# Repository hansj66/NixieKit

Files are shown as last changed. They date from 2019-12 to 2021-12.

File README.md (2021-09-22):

# Nixie Clock Kit 1.3

This repository contains firmware examples and the necessary STEP files for completing the TimeExpander Nixie Clock Kit. 

You will need to patch the 595 driver for the wiringPi and invert the logic before compiling the firmware.

The PDF in the "doc" folder contains assembly instructions / bill of materials

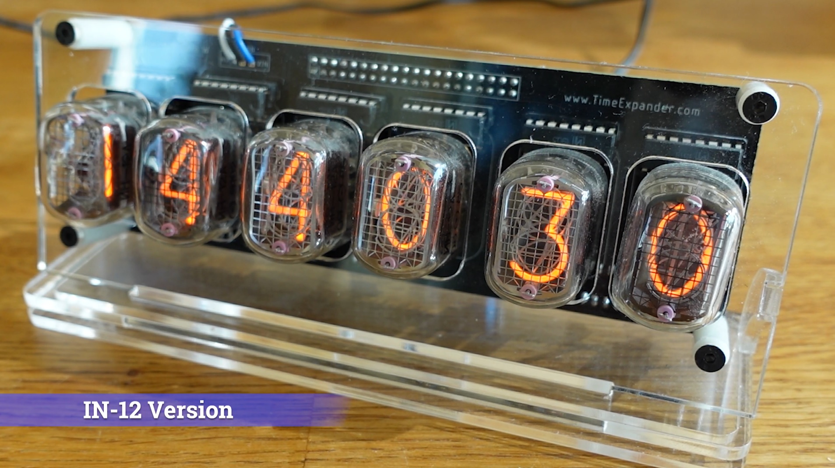
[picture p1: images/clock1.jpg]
clock1


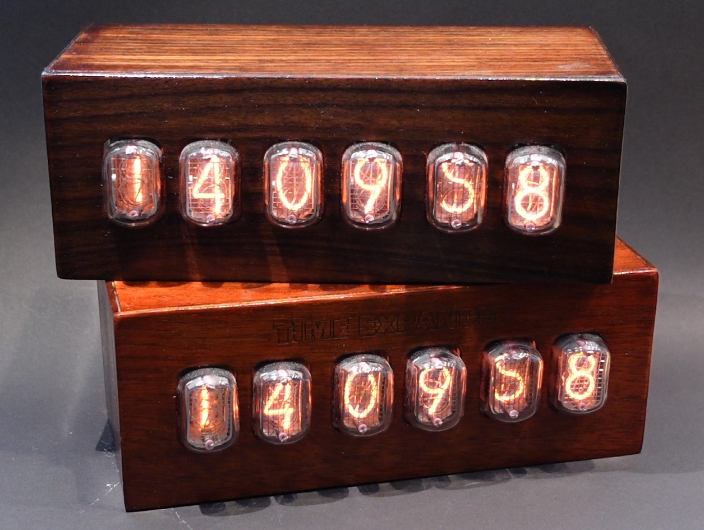
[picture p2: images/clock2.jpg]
clock2


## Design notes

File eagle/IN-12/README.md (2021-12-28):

# Experimental IN-1 variant of the IN-12 clock.

This is pin compatible with the IN-12 clock and will run the same firmware.

# IMPORTANT NOTE

1. The Board is designed for use with Mill-Max pin sockets (Manufacturer Product Number: 0390-0-15-01-08-27-10-0. DigiKey part number: [ED5034-ND](https://www.digikey.no/en/products/detail/mill-max-manufacturing-corp/0390-0-15-01-08-27-10-0/158196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))

2. The alignment of the digits with respect to the pinout have been off by a certain degree on almost all of the tubes that I have tested. I would advise against soldering the mill max sockets to the PCB if you have a limited number of tubes available, since the odds are that the aligment of the digits will vary noticeably between digits.

If you care about perfect alignment of the digits and only have a limited number of IN-1 tubes available, a better option might be to use Molex crimp terminals as pin sockets for the tubes (DigiKey part number [WM1103-ND](https://www.digikey.no/en/products/detail/molex/0002091119/26390?s=N4IgTCBcDaIO4FsCMSAMBmAtAOwCYgF0BfIA)) and run wires between the crimp terminals and the board.

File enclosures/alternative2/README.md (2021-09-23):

# Note

The DXF files are suitable laser cutting parts using 3mm materials

There are no air vents in this design. The clock has been tested in this enclosure for durations of up to 8 hours during mini maker faires.

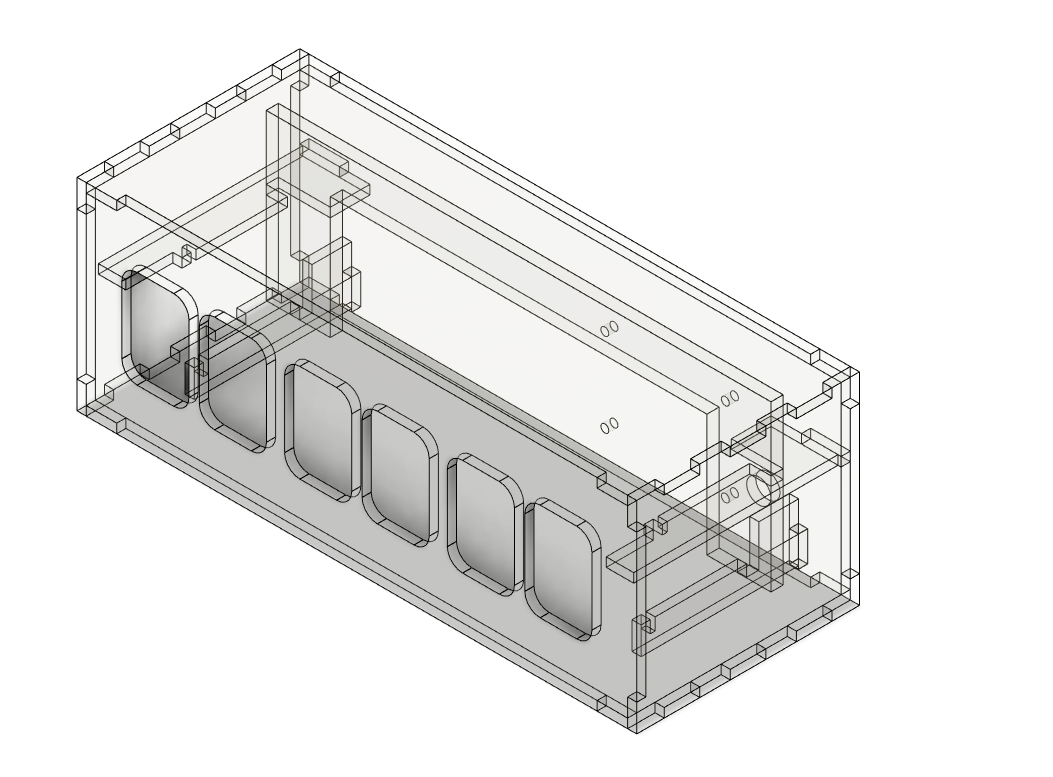
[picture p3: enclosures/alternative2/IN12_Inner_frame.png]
inner frame


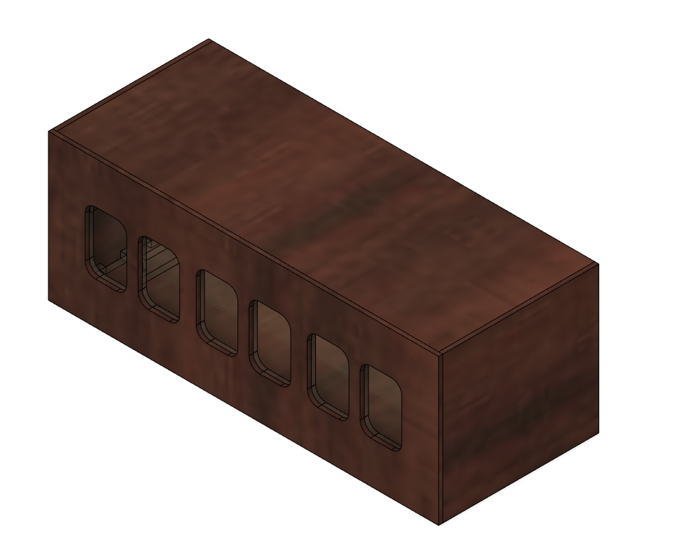
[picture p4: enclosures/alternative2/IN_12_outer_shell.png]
outer shell


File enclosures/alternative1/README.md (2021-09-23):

# Note

The DXF files are suitable laser cutting parts using 3mm materials

# Warning

By mounting the PCB in this frame, the high voltage anode pins will be exposed at the rear.

If using this design, the clock should be placed in a safe area / display cabinet.

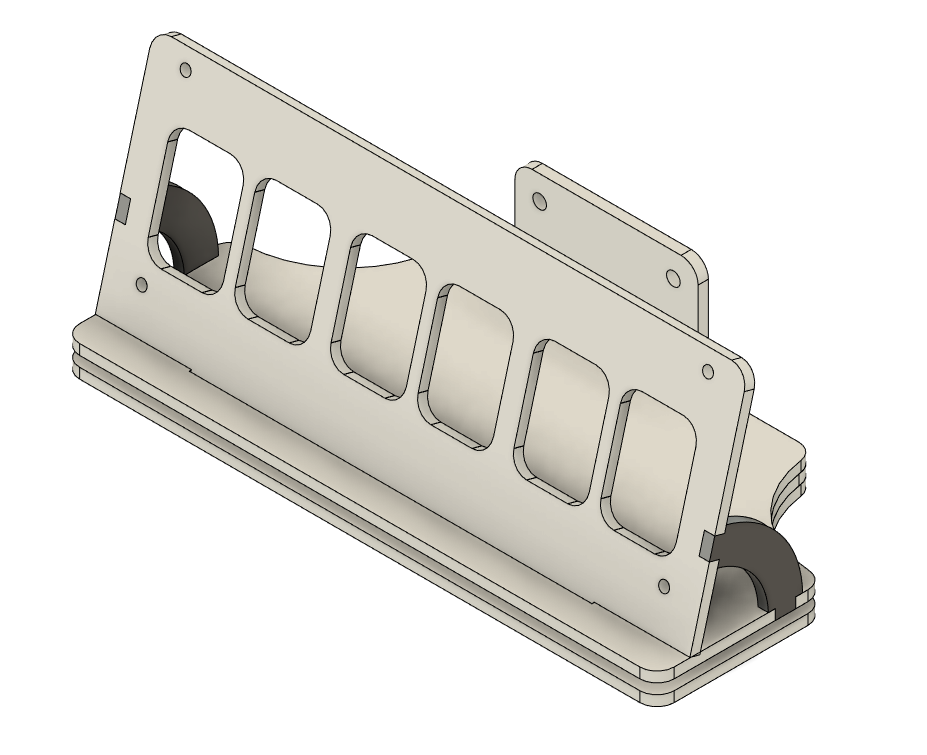
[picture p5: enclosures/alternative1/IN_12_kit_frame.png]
frame


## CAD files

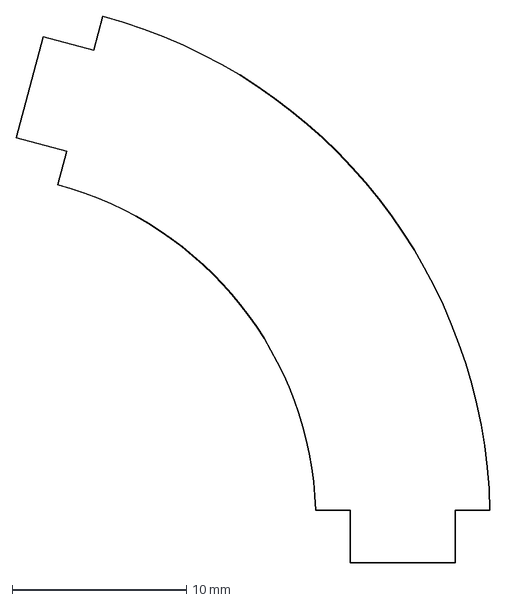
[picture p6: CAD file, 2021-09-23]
enclosures/alternative1/DXF/Side_bracket2.dxf
27.2 x 31.3 mm

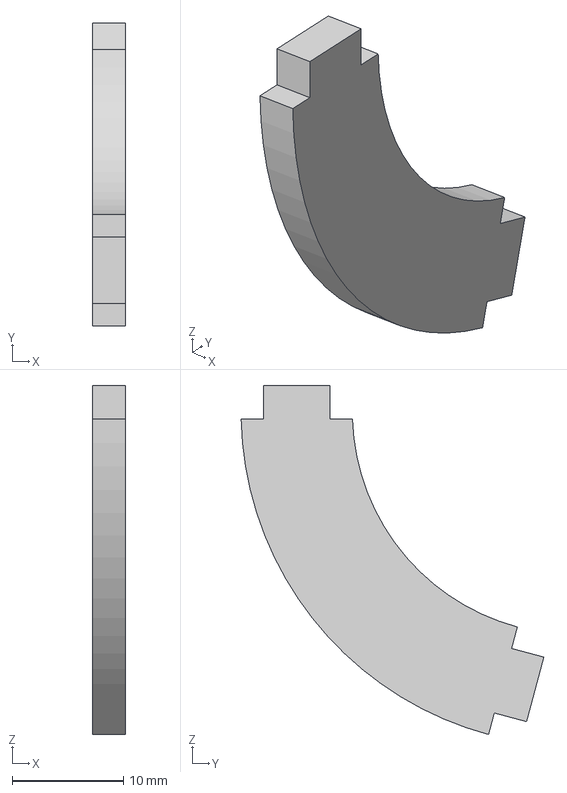
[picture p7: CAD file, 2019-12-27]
enclosures/alternative1/STEP/side1.step
3.00 x 27.2 x 31.3 mm

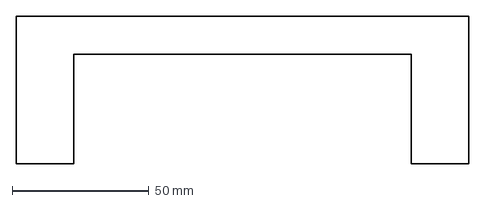
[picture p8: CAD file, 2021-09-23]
enclosures/alternative2/DXF/Rear_bracket.dxf
165.5 x 54.0 mm

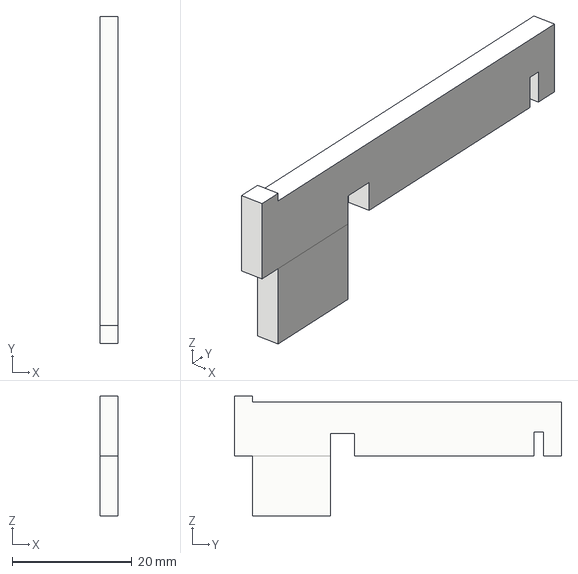
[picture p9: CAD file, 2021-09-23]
enclosures/alternative2/STEP/PCB_Bracket4.step
3.00 x 54.6 x 20.0 mm

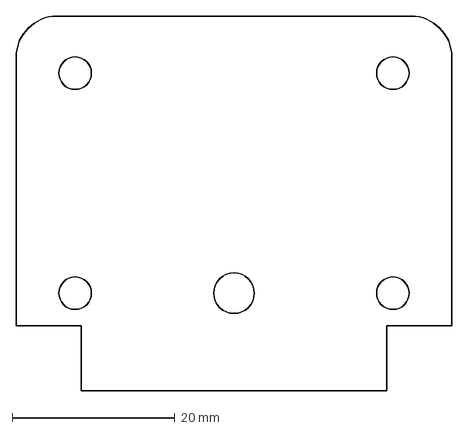
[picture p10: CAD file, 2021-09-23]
enclosures/alternative1/DXF/Power.dxf
53.5 x 46.0 mm

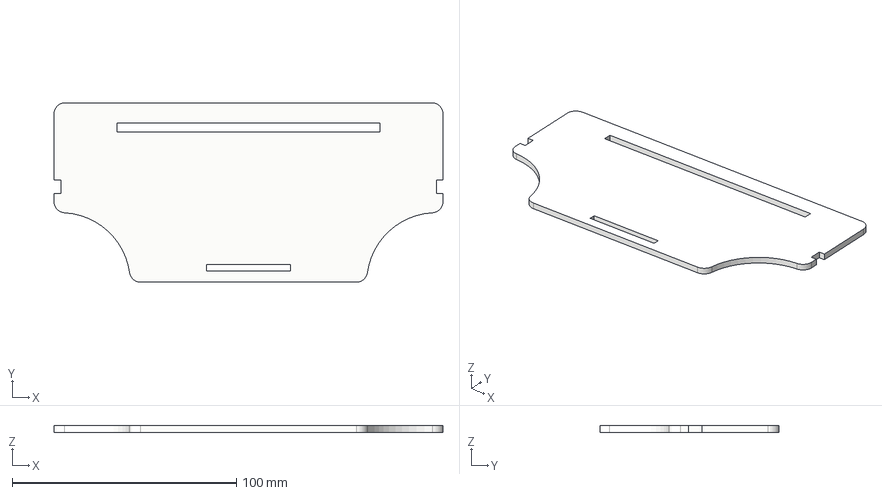
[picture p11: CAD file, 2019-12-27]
enclosures/alternative1/STEP/base_top.step
173.5 x 80.0 x 3.00 mm

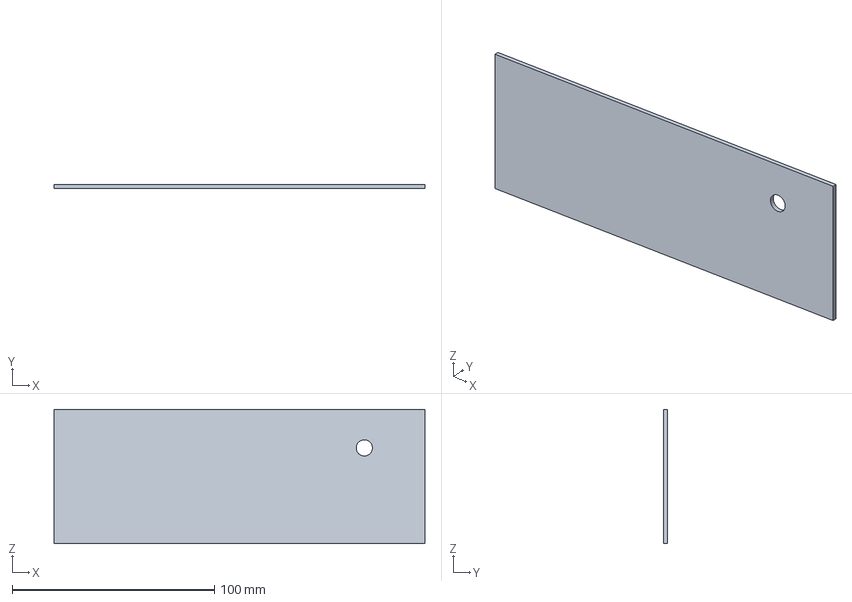
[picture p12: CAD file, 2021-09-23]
enclosures/alternative2/STEP/Wood_Back.step
183.5 x 2.00 x 66.3 mm

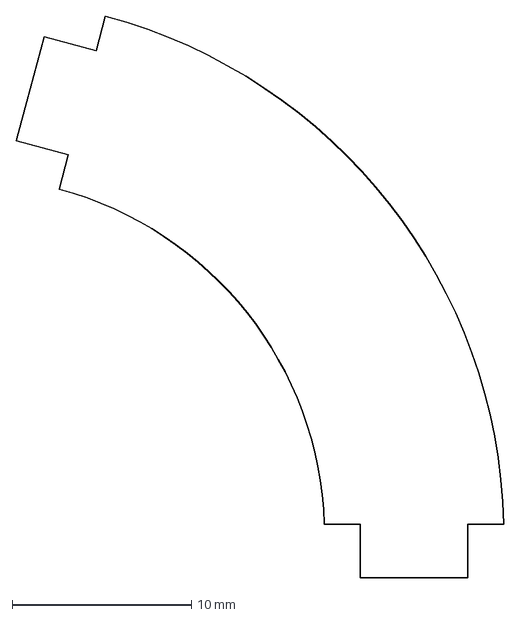
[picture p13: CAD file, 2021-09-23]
enclosures/alternative1/DXF/Side_bracket1.dxf
27.2 x 31.3 mm

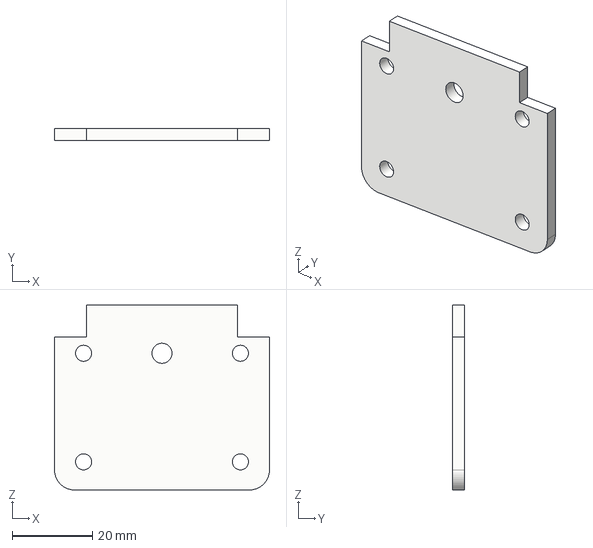
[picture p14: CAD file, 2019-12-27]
enclosures/alternative1/STEP/HV.step
53.5 x 3.00 x 46.0 mm

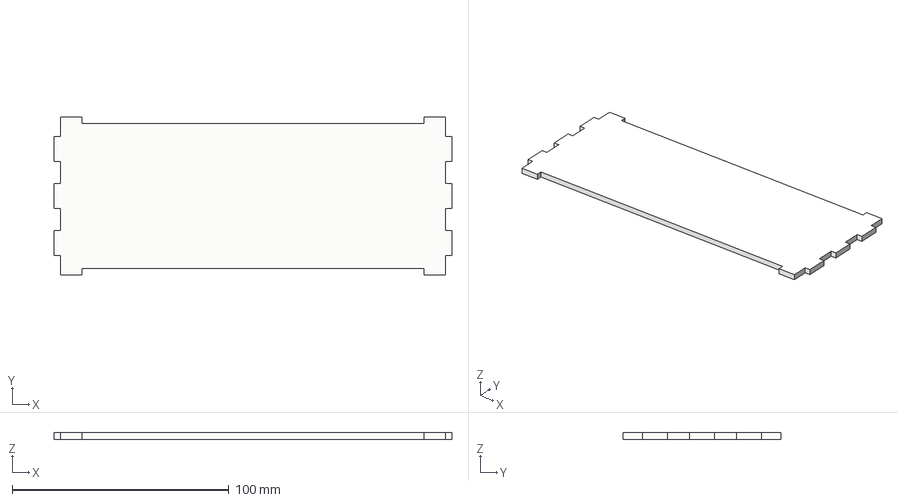
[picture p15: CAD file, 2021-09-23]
enclosures/alternative2/STEP/Bottom.step
183.5 x 73.0 x 3.00 mm

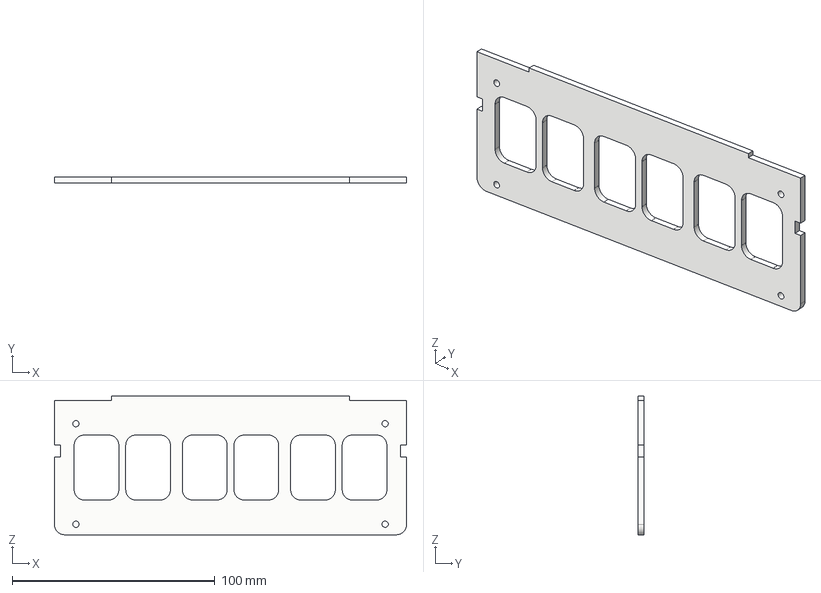
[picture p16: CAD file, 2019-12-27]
enclosures/alternative1/STEP/front.step
173.5 x 3.00 x 68.3 mm

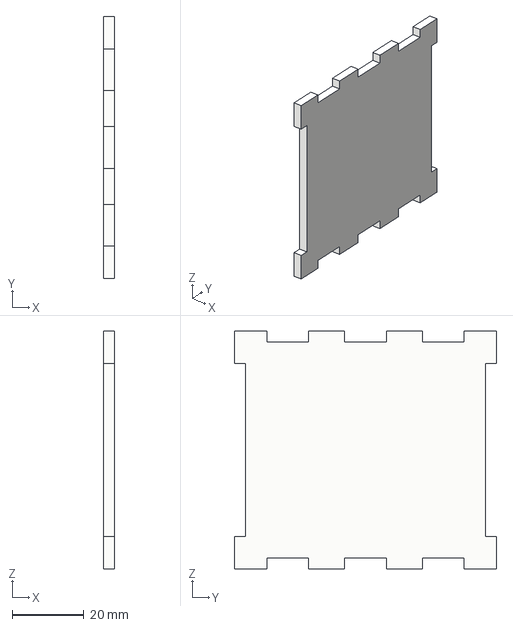
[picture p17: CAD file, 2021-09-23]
enclosures/alternative2/STEP/Right_Side.step
3.00 x 73.0 x 66.3 mm

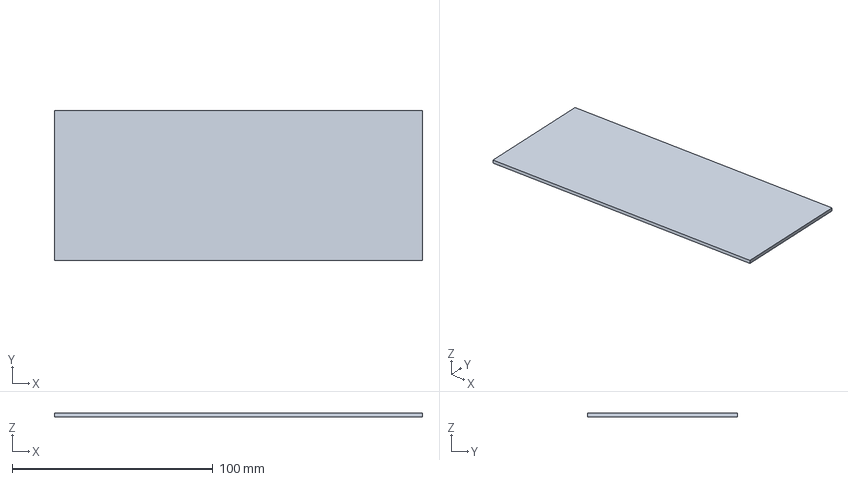
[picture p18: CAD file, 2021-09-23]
enclosures/alternative2/STEP/Wood_Top.step
183.5 x 75.0 x 2.00 mm

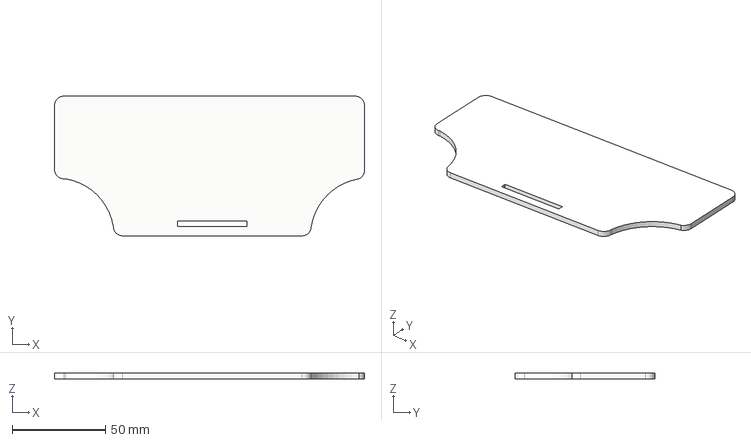
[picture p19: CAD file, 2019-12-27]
enclosures/alternative1/STEP/base_middle.step
166.5 x 75.0 x 3.00 mm

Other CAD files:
enclosures/alternative1/STEP/side2.step
enclosures/alternative2/STEP/Left_Side.step
enclosures/alternative1/STEP/base_bottom.step
enclosures/alternative2/STEP/PCB_Bracket3.step
enclosures/alternative1/DXF/Base_bottom.dxf
enclosures/alternative1/DXF/Base_middle.dxf
enclosures/alternative1/DXF/Base_top.dxf
enclosures/alternative1/DXF/Front.dxf
enclosures/alternative2/DXF/Back.dxf
enclosures/alternative2/DXF/Bottom.dxf
enclosures/alternative2/DXF/Front.dxf
enclosures/alternative2/DXF/Left_Side.dxf
enclosures/alternative2/DXF/PCB_Bracket1.dxf
enclosures/alternative2/DXF/PCB_Bracket2.dxf
enclosures/alternative2/DXF/PCB_Bracket3.dxf
enclosures/alternative2/DXF/PCB_Bracket4.dxf
enclosures/alternative2/DXF/Right_side.dxf
enclosures/alternative2/DXF/Top.dxf
enclosures/alternative2/DXF/Wood_back.dxf
enclosures/alternative2/DXF/Wood_bottom.dxf
enclosures/alternative2/DXF/Wood_front.dxf
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

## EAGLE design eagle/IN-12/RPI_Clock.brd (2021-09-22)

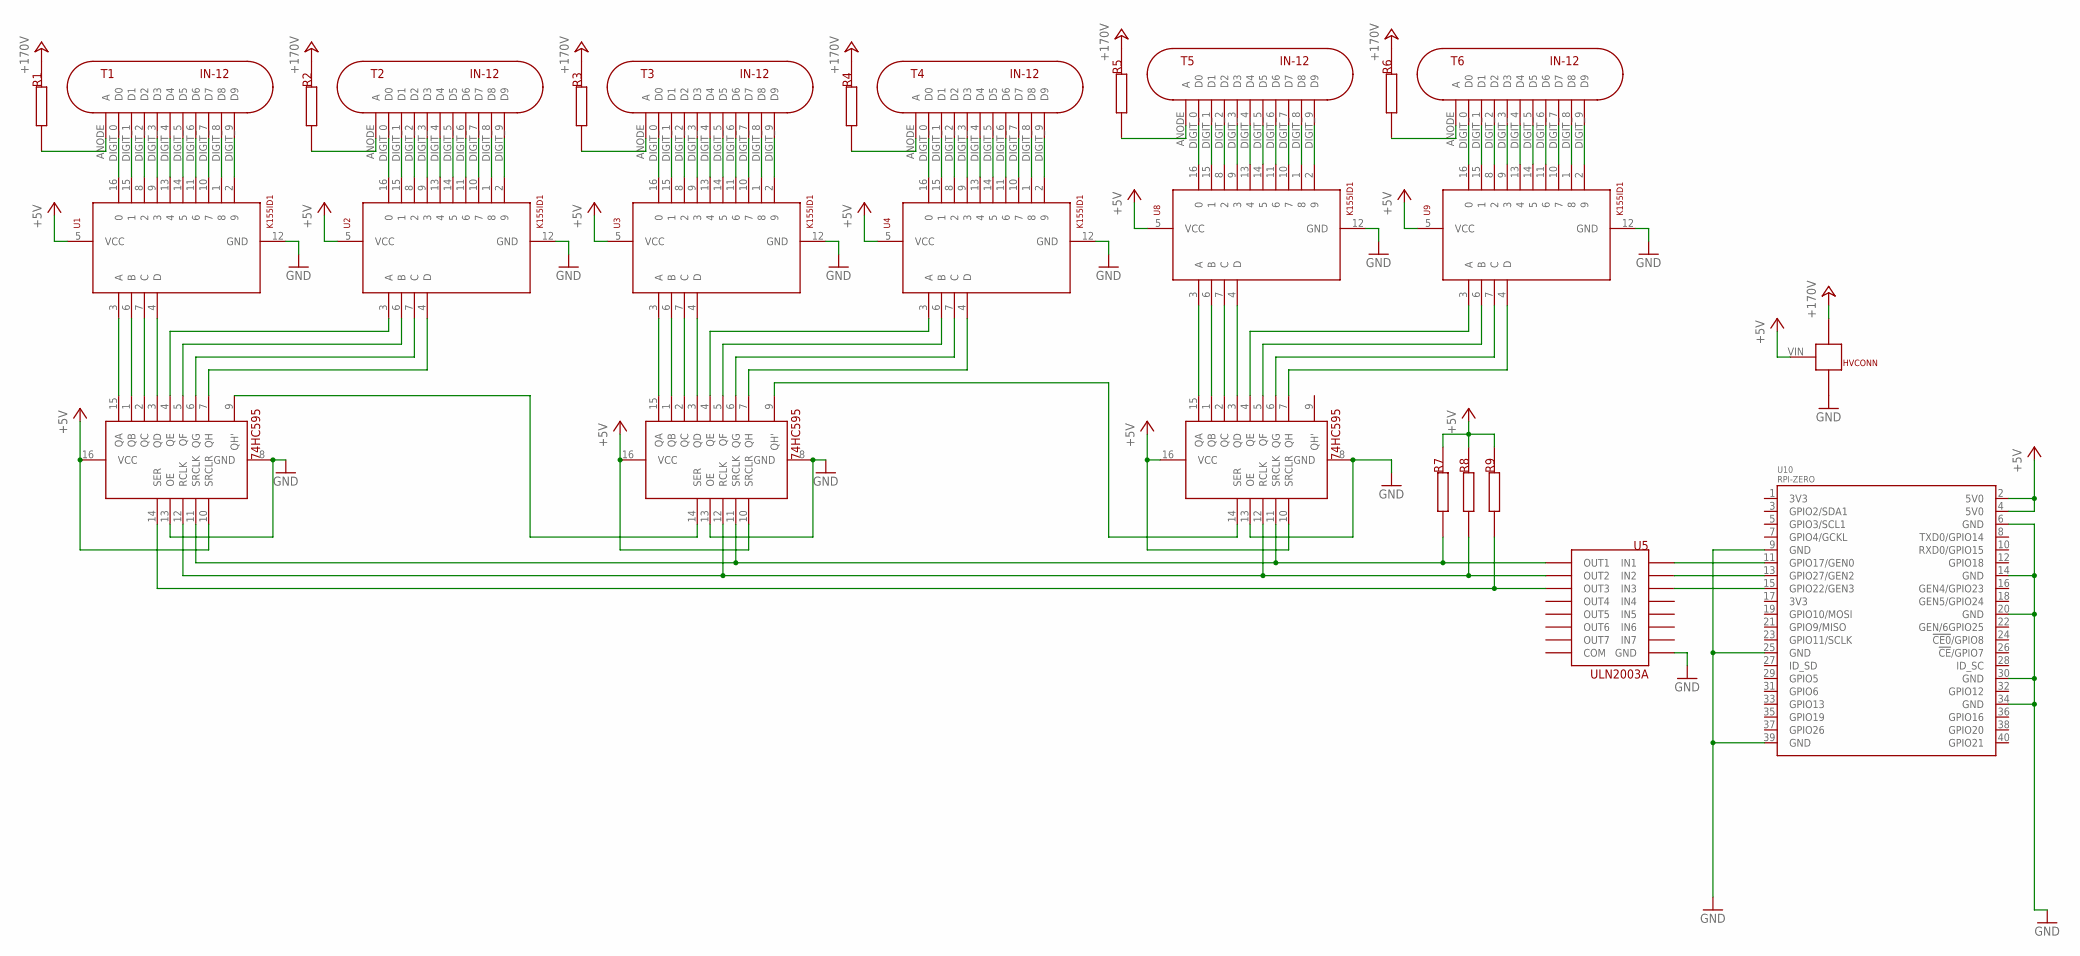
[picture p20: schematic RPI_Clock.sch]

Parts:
HVCONN: HV_CONNECTOR
R1, R2, R3, R4, R5, R6: 5,6K; ANODE_RESISTOR
R7, R8, R9: 10k; ANODE_RESISTOR
T1, T2, T3, T4, T5, T6: IN-12
U1, U2, U3, U4, U8, U9: K155ID1; DIP16-2.54-19.2X7.62MM
U5: ULN2003A; DIL16
U6, U7, U11: 74HC595; DIL16
U10: RPI-ZERO; RASP_PI_ZERO_BOARD_FULL

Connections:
+5V: HVCONN.VIN, R7.P$2, R8.P$2, R9.P$2, U1.5 (VCC), U2.5 (VCC), U3.5 (VCC), U4.5 (VCC), U6.10 (SRCLR), U6.16 (VCC), U7.10 (SRCLR), U7.16 (VCC), U8.5 (VCC), U9.5 (VCC), U10.2 (5V0), U10.4 (5V0), U11.10 (SRCLR), U11.16 (VCC)
+24V: HVCONN.+170V, R1.P$2, R2.P$2, R3.P$2, R4.P$2, R5.P$2, R6.P$2
GND: HVCONN.GND, U1.12 (GND), U2.12 (GND), U3.12 (GND), U4.12 (GND), U5.8 (GND), U6.8 (GND), U6.13 (OE), U7.8 (GND), U7.13 (OE), U8.12 (GND), U9.12 (GND), U10.6 (GND), U10.9 (GND), U10.14 (GND), U10.20 (GND), U10.25 (GND), U10.30 (GND), U10.34 (GND), U10.39 (GND), U11.8 (GND), U11.13 (OE)
unnamed: T1.DIGIT_9 (D9), U1.2 (9)
unnamed: T1.DIGIT_8 (D8), U1.1 (8)
unnamed: T1.DIGIT_7 (D7), U1.10 (7)
unnamed: T1.DIGIT_6 (D6), U1.11 (6)
unnamed: T1.DIGIT_5 (D5), U1.14 (5)
unnamed: T1.DIGIT_4 (D4), U1.13 (4)
unnamed: T1.DIGIT_3 (D3), U1.9 (3)
unnamed: T1.DIGIT_2 (D2), U1.8 (2)
unnamed: T1.DIGIT_1 (D1), U1.15 (1)
unnamed: T1.DIGIT_0 (D0), U1.16 (0)
unnamed: R1.P$1, T1.ANODE (A)
unnamed: T2.DIGIT_9 (D9), U2.2 (9)
unnamed: T2.DIGIT_8 (D8), U2.1 (8)
unnamed: T2.DIGIT_7 (D7), U2.10 (7)
unnamed: T2.DIGIT_6 (D6), U2.11 (6)
unnamed: T2.DIGIT_5 (D5), U2.14 (5)
unnamed: T2.DIGIT_4 (D4), U2.13 (4)
unnamed: T2.DIGIT_3 (D3), U2.9 (3)
unnamed: T2.DIGIT_2 (D2), U2.8 (2)
unnamed: T2.DIGIT_1 (D1), U2.15 (1)
unnamed: T2.DIGIT_0 (D0), U2.16 (0)
unnamed: R2.P$1, T2.ANODE (A)
unnamed: T3.DIGIT_9 (D9), U3.2 (9)
unnamed: T3.DIGIT_8 (D8), U3.1 (8)
unnamed: T3.DIGIT_7 (D7), U3.10 (7)
unnamed: T3.DIGIT_6 (D6), U3.11 (6)
unnamed: T3.DIGIT_5 (D5), U3.14 (5)
unnamed: T3.DIGIT_4 (D4), U3.13 (4)
unnamed: T3.DIGIT_3 (D3), U3.9 (3)
unnamed: T3.DIGIT_2 (D2), U3.8 (2)
unnamed: T3.DIGIT_1 (D1), U3.15 (1)
unnamed: T3.DIGIT_0 (D0), U3.16 (0)
unnamed: R3.P$1, T3.ANODE (A)
unnamed: T4.DIGIT_9 (D9), U4.2 (9)
unnamed: T4.DIGIT_8 (D8), U4.1 (8)
unnamed: T4.DIGIT_7 (D7), U4.10 (7)
unnamed: T4.DIGIT_6 (D6), U4.11 (6)
unnamed: T4.DIGIT_5 (D5), U4.14 (5)
unnamed: T4.DIGIT_4 (D4), U4.13 (4)
unnamed: T4.DIGIT_3 (D3), U4.9 (3)
unnamed: T4.DIGIT_2 (D2), U4.8 (2)
unnamed: T4.DIGIT_1 (D1), U4.15 (1)
unnamed: T4.DIGIT_0 (D0), U4.16 (0)
unnamed: R4.P$1, T4.ANODE (A)
unnamed: U5.1 (IN1), U10.11 (GPIO17/GEN0)
unnamed: U5.2 (IN2), U10.13 (GPIO27/GEN2)
unnamed: R7.P$1, U5.16 (OUT1), U6.11 (SRCLK), U7.11 (SRCLK), U11.11 (SRCLK)
unnamed: R8.P$1, U5.15 (OUT2), U6.12 (RCLK), U7.12 (RCLK), U11.12 (RCLK)
unnamed: R9.P$1, U5.14 (OUT3), U6.14 (SER)
unnamed: U5.3 (IN3), U10.15 (GPIO22/GEN3)
unnamed: T5.DIGIT_9 (D9), U8.2 (9)
unnamed: T5.DIGIT_8 (D8), U8.1 (8)
unnamed: T5.DIGIT_7 (D7), U8.10 (7)
unnamed: T5.DIGIT_6 (D6), U8.11 (6)
unnamed: T5.DIGIT_5 (D5), U8.14 (5)
unnamed: T5.DIGIT_4 (D4), U8.13 (4)
unnamed: T5.DIGIT_3 (D3), U8.9 (3)
unnamed: T5.DIGIT_2 (D2), U8.8 (2)
unnamed: T5.DIGIT_1 (D1), U8.15 (1)
unnamed: T5.DIGIT_0 (D0), U8.16 (0)
unnamed: R5.P$1, T5.ANODE (A)
unnamed: U1.3 (A), U6.15 (QA)
unnamed: U1.6 (B), U6.1 (QB)
unnamed: U1.7 (C), U6.2 (QC)
unnamed: U1.4 (D), U6.3 (QD)
unnamed: U2.3 (A), U6.4 (QE)
unnamed: U2.6 (B), U6.5 (QF)
unnamed: U2.7 (C), U6.6 (QG)
unnamed: U2.4 (D), U6.7 (QH)
unnamed: U3.3 (A), U7.15 (QA)
unnamed: U3.6 (B), U7.1 (QB)
unnamed: U3.7 (C), U7.2 (QC)
unnamed: U3.4 (D), U7.3 (QD)
unnamed: U4.3 (A), U7.4 (QE)
unnamed: U4.6 (B), U7.5 (QF)
unnamed: U4.7 (C), U7.6 (QG)
unnamed: U4.4 (D), U7.7 (QH)
unnamed: T6.DIGIT_9 (D9), U9.2 (9)
unnamed: T6.DIGIT_8 (D8), U9.1 (8)
unnamed: T6.DIGIT_7 (D7), U9.10 (7)
unnamed: T6.DIGIT_6 (D6), U9.11 (6)
unnamed: T6.DIGIT_5 (D5), U9.14 (5)
unnamed: T6.DIGIT_4 (D4), U9.13 (4)
unnamed: T6.DIGIT_3 (D3), U9.9 (3)
unnamed: T6.DIGIT_2 (D2), U9.8 (2)
unnamed: U6.9 (QH'), U7.14 (SER)
unnamed: T6.DIGIT_1 (D1), U9.15 (1)
unnamed: T6.DIGIT_0 (D0), U9.16 (0)
unnamed: R6.P$1, T6.ANODE (A)
unnamed: U8.3 (A), U11.15 (QA)
unnamed: U8.6 (B), U11.1 (QB)
unnamed: U8.7 (C), U11.2 (QC)
unnamed: U8.4 (D), U11.3 (QD)
unnamed: U9.3 (A), U11.4 (QE)
unnamed: U9.6 (B), U11.5 (QF)
unnamed: U9.7 (C), U11.6 (QG)
unnamed: U9.4 (D), U11.7 (QH)
unnamed: U7.9 (QH'), U11.14 (SER)

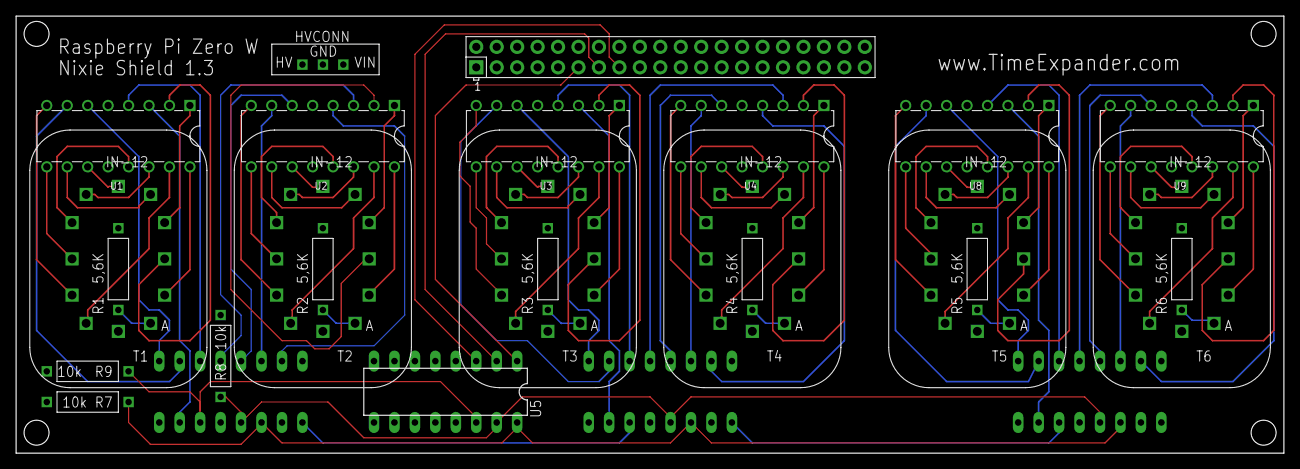
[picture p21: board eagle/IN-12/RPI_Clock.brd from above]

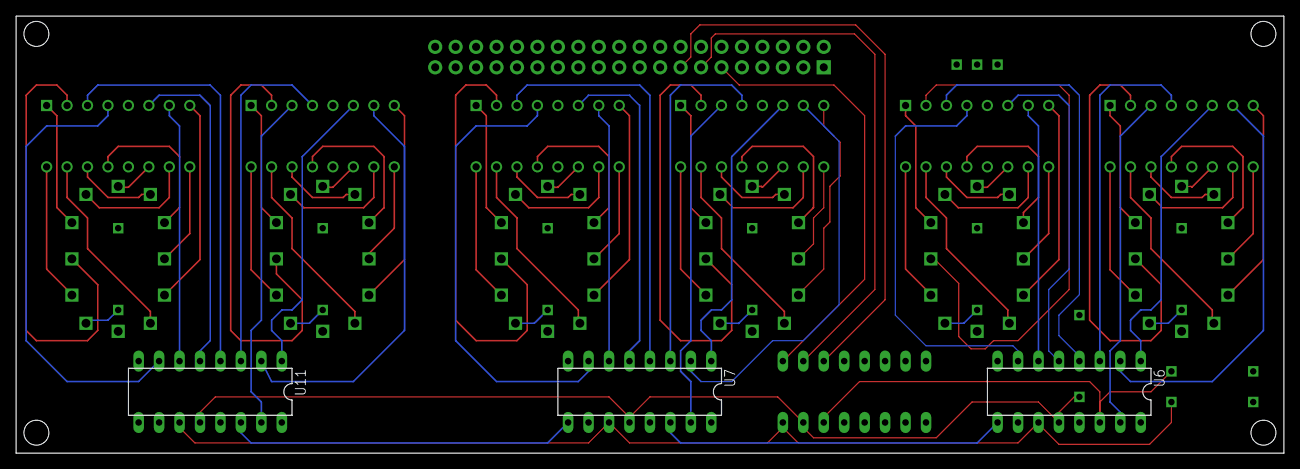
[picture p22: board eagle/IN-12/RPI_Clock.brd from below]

Board: 4 copper layers, 157.5 x 54.3 mm, 27 parts (3 on the bottom side), 101 nets.

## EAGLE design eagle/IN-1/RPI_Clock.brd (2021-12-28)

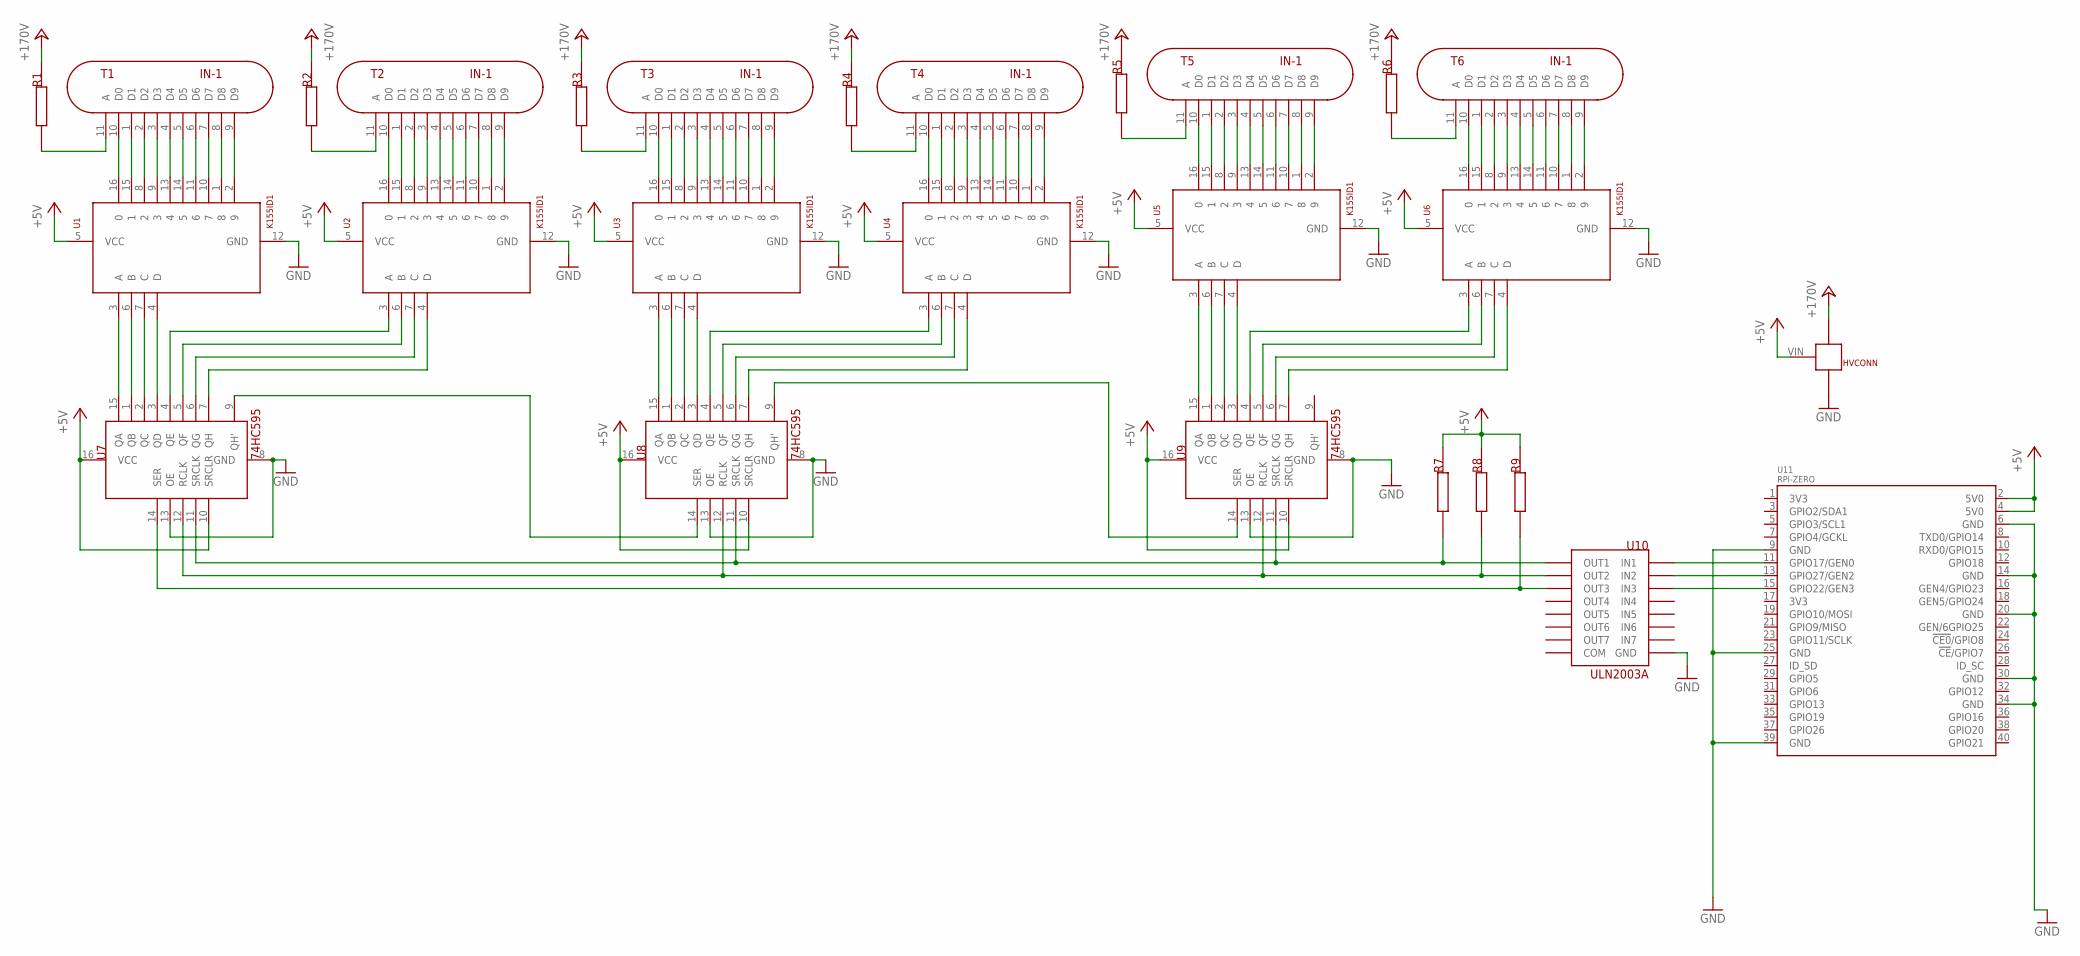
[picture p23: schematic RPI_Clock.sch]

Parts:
HVCONN: HV_CONNECTOR
R1, R2, R3, R4, R5, R6: 5,6K; ANODE_RESISTOR
R7, R8, R9: 10k; ANODE_RESISTOR
T1, T2, T3, T4, T5, T6: IN-1
U1, U2, U3, U4, U5, U6: K155ID1; DIP16-2.54-19.2X7.62MM
U7, U8, U9: 74HC595; DIL16
U10: ULN2003A; DIL16
U11: RPI-ZERO; RASP_PI_ZERO_BOARD_FULL

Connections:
+5V: HVCONN.VIN, R7.P$2, R8.P$2, R9.P$2, U1.5 (VCC), U2.5 (VCC), U3.5 (VCC), U4.5 (VCC), U5.5 (VCC), U6.5 (VCC), U7.10 (SRCLR), U7.16 (VCC), U8.10 (SRCLR), U8.16 (VCC), U9.10 (SRCLR), U9.16 (VCC), U11.2 (5V0), U11.4 (5V0)
+24V: HVCONN.+170V, R1.P$2, R2.P$2, R3.P$2, R4.P$2, R5.P$2, R6.P$2
GND: HVCONN.GND, U1.12 (GND), U2.12 (GND), U3.12 (GND), U4.12 (GND), U5.12 (GND), U6.12 (GND), U7.8 (GND), U7.13 (OE), U8.8 (GND), U8.13 (OE), U9.8 (GND), U9.13 (OE), U10.8 (GND), U11.6 (GND), U11.9 (GND), U11.14 (GND), U11.20 (GND), U11.25 (GND), U11.30 (GND), U11.34 (GND), U11.39 (GND)
unnamed: T1.9 (D9), U1.2 (9)
unnamed: T1.8 (D8), U1.1 (8)
unnamed: T1.7 (D7), U1.10 (7)
unnamed: T1.6 (D6), U1.11 (6)
unnamed: T1.5 (D5), U1.14 (5)
unnamed: T1.4 (D4), U1.13 (4)
unnamed: T1.3 (D3), U1.9 (3)
unnamed: T1.2 (D2), U1.8 (2)
unnamed: T1.1 (D1), U1.15 (1)
unnamed: T1.10 (D0), U1.16 (0)
unnamed: R1.P$1, T1.11 (A)
unnamed: T2.9 (D9), U2.2 (9)
unnamed: T2.8 (D8), U2.1 (8)
unnamed: T2.7 (D7), U2.10 (7)
unnamed: T2.6 (D6), U2.11 (6)
unnamed: T2.5 (D5), U2.14 (5)
unnamed: T2.4 (D4), U2.13 (4)
unnamed: T2.3 (D3), U2.9 (3)
unnamed: T2.2 (D2), U2.8 (2)
unnamed: T2.1 (D1), U2.15 (1)
unnamed: T2.10 (D0), U2.16 (0)
unnamed: R2.P$1, T2.11 (A)
unnamed: T3.9 (D9), U3.2 (9)
unnamed: T3.8 (D8), U3.1 (8)
unnamed: T3.7 (D7), U3.10 (7)
unnamed: T3.6 (D6), U3.11 (6)
unnamed: T3.5 (D5), U3.14 (5)
unnamed: T3.4 (D4), U3.13 (4)
unnamed: T3.3 (D3), U3.9 (3)
unnamed: T3.2 (D2), U3.8 (2)
unnamed: T3.1 (D1), U3.15 (1)
unnamed: T3.10 (D0), U3.16 (0)
unnamed: R3.P$1, T3.11 (A)
unnamed: T4.9 (D9), U4.2 (9)
unnamed: T4.8 (D8), U4.1 (8)
unnamed: T4.7 (D7), U4.10 (7)
unnamed: T4.6 (D6), U4.11 (6)
unnamed: T4.5 (D5), U4.14 (5)
unnamed: T4.4 (D4), U4.13 (4)
unnamed: T4.3 (D3), U4.9 (3)
unnamed: T4.2 (D2), U4.8 (2)
unnamed: T4.1 (D1), U4.15 (1)
unnamed: T4.10 (D0), U4.16 (0)
unnamed: R4.P$1, T4.11 (A)
unnamed: U10.1 (IN1), U11.11 (GPIO17/GEN0)
unnamed: U10.2 (IN2), U11.13 (GPIO27/GEN2)
unnamed: R7.P$1, U7.11 (SRCLK), U8.11 (SRCLK), U9.11 (SRCLK), U10.16 (OUT1)
unnamed: R8.P$1, U7.12 (RCLK), U8.12 (RCLK), U9.12 (RCLK), U10.15 (OUT2)
unnamed: R9.P$1, U7.14 (SER), U10.14 (OUT3)
unnamed: U10.3 (IN3), U11.15 (GPIO22/GEN3)
unnamed: T5.9 (D9), U5.2 (9)
unnamed: T5.8 (D8), U5.1 (8)
unnamed: T5.7 (D7), U5.10 (7)
unnamed: T5.6 (D6), U5.11 (6)
unnamed: T5.5 (D5), U5.14 (5)
unnamed: T5.4 (D4), U5.13 (4)
unnamed: T5.3 (D3), U5.9 (3)
unnamed: T5.2 (D2), U5.8 (2)
unnamed: T5.1 (D1), U5.15 (1)
unnamed: T5.10 (D0), U5.16 (0)
unnamed: R5.P$1, T5.11 (A)
unnamed: U1.3 (A), U7.15 (QA)
unnamed: U1.6 (B), U7.1 (QB)
unnamed: U1.7 (C), U7.2 (QC)
unnamed: U1.4 (D), U7.3 (QD)
unnamed: U2.3 (A), U7.4 (QE)
unnamed: U2.6 (B), U7.5 (QF)
unnamed: U2.7 (C), U7.6 (QG)
unnamed: U2.4 (D), U7.7 (QH)
unnamed: U3.3 (A), U8.15 (QA)
unnamed: U3.6 (B), U8.1 (QB)
unnamed: U3.7 (C), U8.2 (QC)
unnamed: U3.4 (D), U8.3 (QD)
unnamed: U4.3 (A), U8.4 (QE)
unnamed: U4.6 (B), U8.5 (QF)
unnamed: U4.7 (C), U8.6 (QG)
unnamed: U4.4 (D), U8.7 (QH)
unnamed: T6.9 (D9), U6.2 (9)
unnamed: T6.8 (D8), U6.1 (8)
unnamed: T6.7 (D7), U6.10 (7)
unnamed: T6.6 (D6), U6.11 (6)
unnamed: T6.5 (D5), U6.14 (5)
unnamed: T6.4 (D4), U6.13 (4)
unnamed: T6.3 (D3), U6.9 (3)
unnamed: T6.2 (D2), U6.8 (2)
unnamed: U7.9 (QH'), U8.14 (SER)
unnamed: T6.1 (D1), U6.15 (1)
unnamed: T6.10 (D0), U6.16 (0)
unnamed: R6.P$1, T6.11 (A)
unnamed: U5.3 (A), U9.15 (QA)
unnamed: U5.6 (B), U9.1 (QB)
unnamed: U5.7 (C), U9.2 (QC)
unnamed: U5.4 (D), U9.3 (QD)
unnamed: U6.3 (A), U9.4 (QE)
unnamed: U6.6 (B), U9.5 (QF)
unnamed: U6.7 (C), U9.6 (QG)
unnamed: U6.4 (D), U9.7 (QH)
unnamed: U8.9 (QH'), U9.14 (SER)

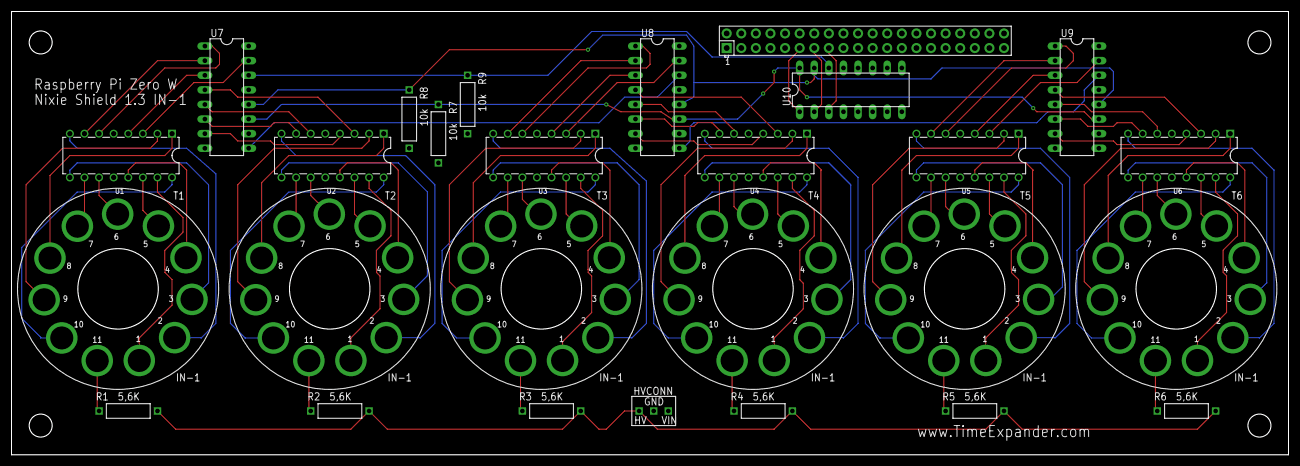
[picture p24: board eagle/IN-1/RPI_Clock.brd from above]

Board: 4 copper layers, 222.2 x 77.1 mm, 27 parts (0 on the bottom side), 101 nets.

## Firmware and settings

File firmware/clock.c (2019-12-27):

#include <unistd.h>
#include <wiringPi.h>
#include <sr595.h>
#include <stdio.h>
#include <time.h>
#include <sys/time.h>
#include <stdlib.h> 
#include <string.h>
#include <sys/types.h>
#include <sys/socket.h>
#include <sys/ioctl.h>
#include <netinet/in.h>
#include <net/if.h>
#include <arpa/inet.h>

// 74HC595 pinout
// pin 14: SER/DS
// pin 12: RCLK/STCP
// pin 11: SRCLK/SHCP

#define SRCLK 0 	// GPIO 17
#define RCLK 2 		// GPIO 27
#define SER 3 		// GPIO 22

#define BASE_PIN 100
#define NUM_PINS 24
#define NUM_DIGITS 6
#define K155ID1_INPUTS 4 

unsigned char DIGIT[10][K155ID1_INPUTS] = {
	{0,0,0,0},
	{1,0,0,0},
	{0,1,0,0},
	{1,1,0,0},
	{0,0,1,0},
	{1,0,1,0},
	{0,1,1,0},
	{1,1,1,0},
	{0,0,0,1},
	{1,0,0,1}
};

unsigned char BUFFER[NUM_DIGITS*K155ID1_INPUTS] = {
	0,0,0,0,
	0,0,0,0,
	0,0,0,0,
	0,0,0,0,
	0,0,0,0,
	0,0,0,0,
};


void testDigit(int pos, int value)
{
	digitalWrite(pos++, DIGIT[value][0]);
	digitalWrite(pos++, DIGIT[value][1]);
	digitalWrite(pos++, DIGIT[value][2]);
	digitalWrite(pos++, DIGIT[value][3]);
}


void mapNumberToBuffer(int rmdr)
{
	int dvsr;
	int quot;
    	dvsr = 100000;
    
	int index = 0;	
	while(dvsr)
	{                     
        	quot = rmdr / dvsr;
         	BUFFER[index] = DIGIT[quot][0];
         	BUFFER[index+1] = DIGIT[quot][1];
         	BUFFER[index+2] = DIGIT[quot][2];
         	BUFFER[index+3] = DIGIT[quot][3];
		index += 4;		
		rmdr %= dvsr;
        	dvsr /= 10;
    	}
}


int getAddress() 
{
	int fd;
	struct ifreq ifr;

	fd = socket(AF_INET, SOCK_DGRAM, 0);
	ifr.ifr_addr.sa_family = AF_INET;
	strncpy(ifr.ifr_name, "wlan0", IFNAMSIZ-1);
	ioctl(fd, SIOCGIFADDR, &ifr);
	close(fd);

	char * addr;
	if (NULL == (addr = strrchr(inet_ntoa(((struct sockaddr_in *)&ifr.ifr_addr)->sin_addr), '.' ))) {
		return 0;
	}
	addr++;
	printf("ADDR: %s\n", addr);
	return atoi(addr); 
}

void displayIP() 
{
	int base = BASE_PIN;
	mapNumberToBuffer(getAddress());
 	for (int i=0; i<NUM_DIGITS*K155ID1_INPUTS; i++)
	{
		digitalWrite(base+i, BUFFER[i]);
		delay(2);
	}
}


int main(void)
{
	wiringPiSetup();
 	sr595Setup (BASE_PIN, NUM_PINS, SER, SRCLK, RCLK);
	int base = BASE_PIN;

	displayIP();
	delay(10000);	

	for (;;) {	
		struct timeval tv;
 		struct tm* ptm;
 		gettimeofday (&tv, NULL);
 		ptm = localtime (&tv.tv_sec);

		mapNumberToBuffer((ptm->tm_hour+1)*10000+ptm->tm_min*100+ptm->tm_sec);
		for (int i=0; i<NUM_DIGITS*K155ID1_INPUTS; i++)
		{
			digitalWrite(base+i, BUFFER[i]);
		
			delay(2);
		}
	}	
	return 0;
}

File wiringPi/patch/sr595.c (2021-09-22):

/*
 * sr595.c:
 *	Extend wiringPi with the 74x595 shift register as a GPIO
 *	expander chip.
 *	Note that the code can cope with a number of 595's
 *	daisy-chained together - up to 4 for now as we're storing
 *	the output "register" in a single unsigned int.
 *
 *	Copyright (c) 2013 Gordon Henderson
 ***********************************************************************
 * This file is part of wiringPi:
 *	https://projects.drogon.net/raspberry-pi/wiringpi/
 *
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
 *    You should have received a copy of the GNU Lesser General Public
 *    License along with wiringPi.
 *    If not, see <http://www.gnu.org/licenses/>.
 ***********************************************************************
 */

#include <stdio.h>
#include <stdint.h>

#include "wiringPi.h"

#include "sr595.h"


/*
 * myDigitalWrite:
 *********************************************************************************
 */

static void myDigitalWrite (struct wiringPiNodeStruct *node, int pin, int value)
{
  unsigned int mask ;
  int  dataPin, clockPin, latchPin ;
  int  bit, bits, output ;

  pin     -= node->pinBase ;				// Normalise pin number
  bits     = node->pinMax - node->pinBase + 1 ;		// ie. number of clock pulses
  dataPin  = node->data0 ;
  clockPin = node->data1 ;
  latchPin = node->data2 ;
  output   = node->data3 ;

  mask = 1 << pin ;

  if (value == HIGH)
    output &= (~mask) ;
  else
    output |=   mask ;

  node->data3 = output ;

// A low -> high latch transition copies the latch to the output pins

  digitalWrite (latchPin, HIGH) ; delayMicroseconds (1) ;
    for (bit = bits - 1 ; bit >= 0 ; --bit)
    {
      digitalWrite (dataPin, output & (1 << bit)) ;

      digitalWrite (clockPin, LOW) ; delayMicroseconds (1) ;
      digitalWrite (clockPin, HIGH) ;  delayMicroseconds (1) ;
    }
  digitalWrite (latchPin, LOW) ; delayMicroseconds (1) ;
}


/*
 * sr595Setup:
 *	Create a new instance of a 74x595 shift register GPIO expander.
 *********************************************************************************
 */

int sr595Setup (const int pinBase, const int numPins,
	const int dataPin, const int clockPin, const int latchPin) 
{
  struct wiringPiNodeStruct *node ;

  node = wiringPiNewNode (pinBase, numPins) ;

  node->data0           = dataPin ;
  node->data1           = clockPin ;
  node->data2           = latchPin ;
  node->data3           = 0 ;		// Output register
  node->digitalWrite    = myDigitalWrite ;

// Initialise the underlying hardware

  digitalWrite (dataPin,  HIGH) ;
  digitalWrite (clockPin, HIGH) ;
  digitalWrite (latchPin, LOW) ;

  pinMode (dataPin,  OUTPUT) ;
  pinMode (clockPin, OUTPUT) ;
  pinMode (latchPin, OUTPUT) ;

  return TRUE ;
}

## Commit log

2019-12-27 Added firmware example and STEP files
    [HV.step, base_bottom.step, base_middle.step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]
2021-09-13 Added Eagle CAD files
    * Added bill of materials and assembly instructions
    [RPI_Clock.brd, RPI_Clock.sch]
2021-09-22 Updated Eagle design files with 1.3 version
    [RPI_Clock.brd, RPI_Clock.sch]
2021-09-22 Added modified 595 driver for wiringPi
    * Necessary beacuse of the ULN2003 (inverting logic)
    [sr595.c]
2021-09-23 Added DXF files for enclosures
    * Also added alternative enclosure
    [Back.dxf, Back.step, Backplane.step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]
2021-12-28 Added experimental IN-1 variant of the nixie clock
    [RPI_Clock.brd, RPI_Clock.sch]
2021-12-28 Added library with nixie symbols and footprints
    * IN-1
    * IN-2
    * IN-12

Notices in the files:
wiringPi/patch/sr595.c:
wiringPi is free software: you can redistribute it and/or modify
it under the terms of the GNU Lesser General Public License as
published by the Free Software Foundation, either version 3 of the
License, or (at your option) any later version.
